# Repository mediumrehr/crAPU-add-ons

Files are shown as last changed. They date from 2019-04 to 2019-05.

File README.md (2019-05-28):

# crAPU-add-ons
a crappy Audio Processing Unit SAO for DEF CON 26 badges; specifically, the zinthesizer was designed for the [DCZia DC26 badge](https://github.com/dczia/Defcon26-Badge) and the scaremin was designed for [Chris Gammell's](https://twitter.com/Chris_Gammell) Goodfear badge.

[video demo](https://www.youtube.com/watch?v=xHMZxM6m_c0)

crAPUs were designed to add audio sythesis/playback capabilities to badges that didn't have any. Since i2c would not be fast enough to drive an external digital to analog converter (DAC), the crAPUs feature their own processor (SAM21G18) to generate tones, and the note and volume can be selected over i2c.

## Installing/Updating Firmware

### Setup

Firmware can be loaded with [Atmel Studio 7.0](https://www.microchip.com/mplab/avr-support/atmel-studio-7), or install the packages below to use with your preferred text editor and compile with arm gcc.

#### arm gcc and gdb

MacOS

```
brew install armmbed/formulae/arm-none-eabi-gcc
```

#### jlink gdb server

Download install file from [segger.com](https://www.segger.com/products/debug-probes/j-link/tools/j-link-gdb-server/about-j-link-gdb-server/)

#### SWD connection

Software debug (SWD) pins are labelled on the back-right of the boards. Connect SWDIO, SWCLK, 3V3, RESET, and GND as labelled. SWD requires the board to be powered external from the SWD port, so it's easiest to power the board from the 3V3 and GND pins on the SAO header.

### Build

```
cd firmware/crAPU/
make -C Build/
```

### Load

#### jlink

Start jlink gdb server in one tab

```
JLinkGDBServer -if SWD -device ATSAMD21G18
```

Start gdb in another tba

```
arm-none-eabi-gdb Build/crAPU.elf
(gdb) target extended-remote :2331
```

Load new firmware, reset microcontroller, and run new code

```
(gdb) load
(gdb) monitor reset
(gdb) c
```

## Usage

The crAPU can be controlled via i2c at address `0x1A`. The add-on will listen for two bytes, the first byte will set the note (0 - 127 using MIDI table), and the second byte will set the volume (0 - 127). If `128 (0x80)` is sent as the MIDI note, it will be interpreted as a note off command.

#### DCZia Badge

Load my [DCZia fork](https://github.com/mediumrehr/Defcon26-Badge) onto the DCZia badge. Attach the zinthesizer add-on, turn on the badge, and within menu mode, select button 7 (left column, third down). The display should now say it's in zinthesizer mode and each key will play a unique note.

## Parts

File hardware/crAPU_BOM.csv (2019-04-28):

DEF CON 26 crAPU Add-on Bill of Materials
April 2019
@mediumrehr
Part | Value | Package | Part Number | Description | Digikey link | notes
C1, 6, 8, 10-12 | 0.1uF | 603 |  | Capacitor
C2 | 0.33uF | 603 |  | Capacitor
C4 | 1uF | 603 |  | Capacitor
C7, 9 | 22pF | 603 |  | Capacitor
D1-3 | white | 1206 |  | LED
J1, (2)* | 2x2 | 0.1" pitch |  | SAO Male header Connector |  | *scaremin requires one; zinthesizer requires two
J3 | 8Ohm/800mW | 15mm Dia. |  | speaker | https://www.digikey.com/product-detail/en/soberton-inc/SP-1504/433-1106-ND/3973690
L1 | FB - 30Ohm | 603 |  | Inductor
R1, 2, 11 | 20K | 805 |  | Resistor
R3-5 | 100 | 603 |  | Resistor
U1 |  | 8-SOIC | LM4862 | IC AMP AUDIO PWR .825W | https://www.digikey.com/product-detail/en/texas-instruments/LM4862MX-NOPB/LM4862MX-NOPBCT-ND/3526986
U4 |  | 48-TQFP | ATSAMD21G18A | IC MCU 32BIT 256KB FLASH | https://www.digikey.com/product-detail/en/microchip-technology/ATSAMD21G18A-AUT/ATSAMD21G18A-AUTCT-ND/4878879
Y1 | 32.768KHz | 2-SMD | ABS06-127-32.768KHZ-T | Crystal | https://www.digikey.com/product-detail/en/abracon-llc/ABS06-127-32.768KHZ-T/535-14513-1-ND/8827204

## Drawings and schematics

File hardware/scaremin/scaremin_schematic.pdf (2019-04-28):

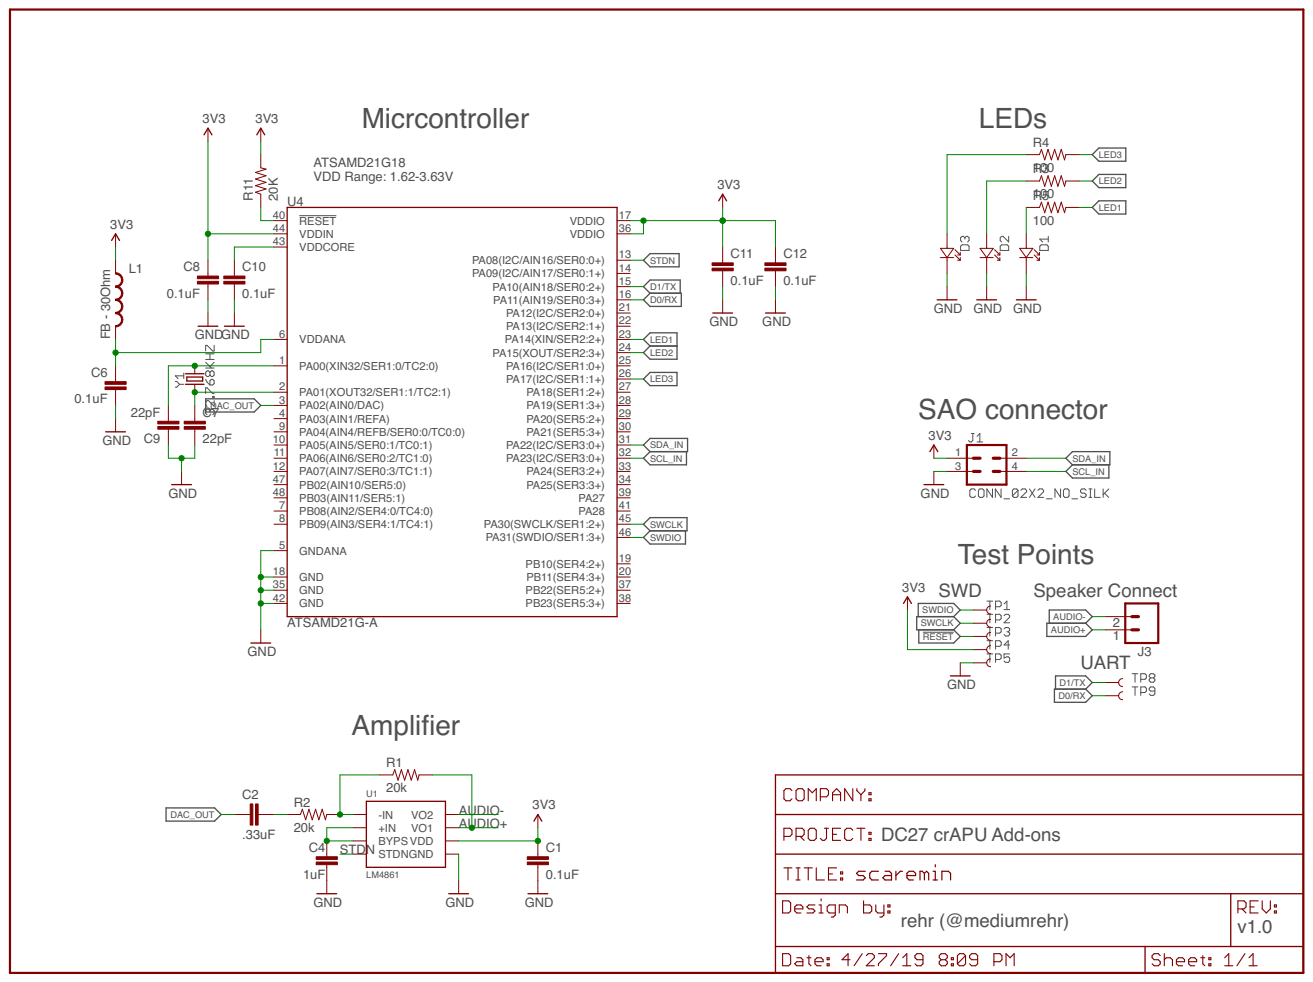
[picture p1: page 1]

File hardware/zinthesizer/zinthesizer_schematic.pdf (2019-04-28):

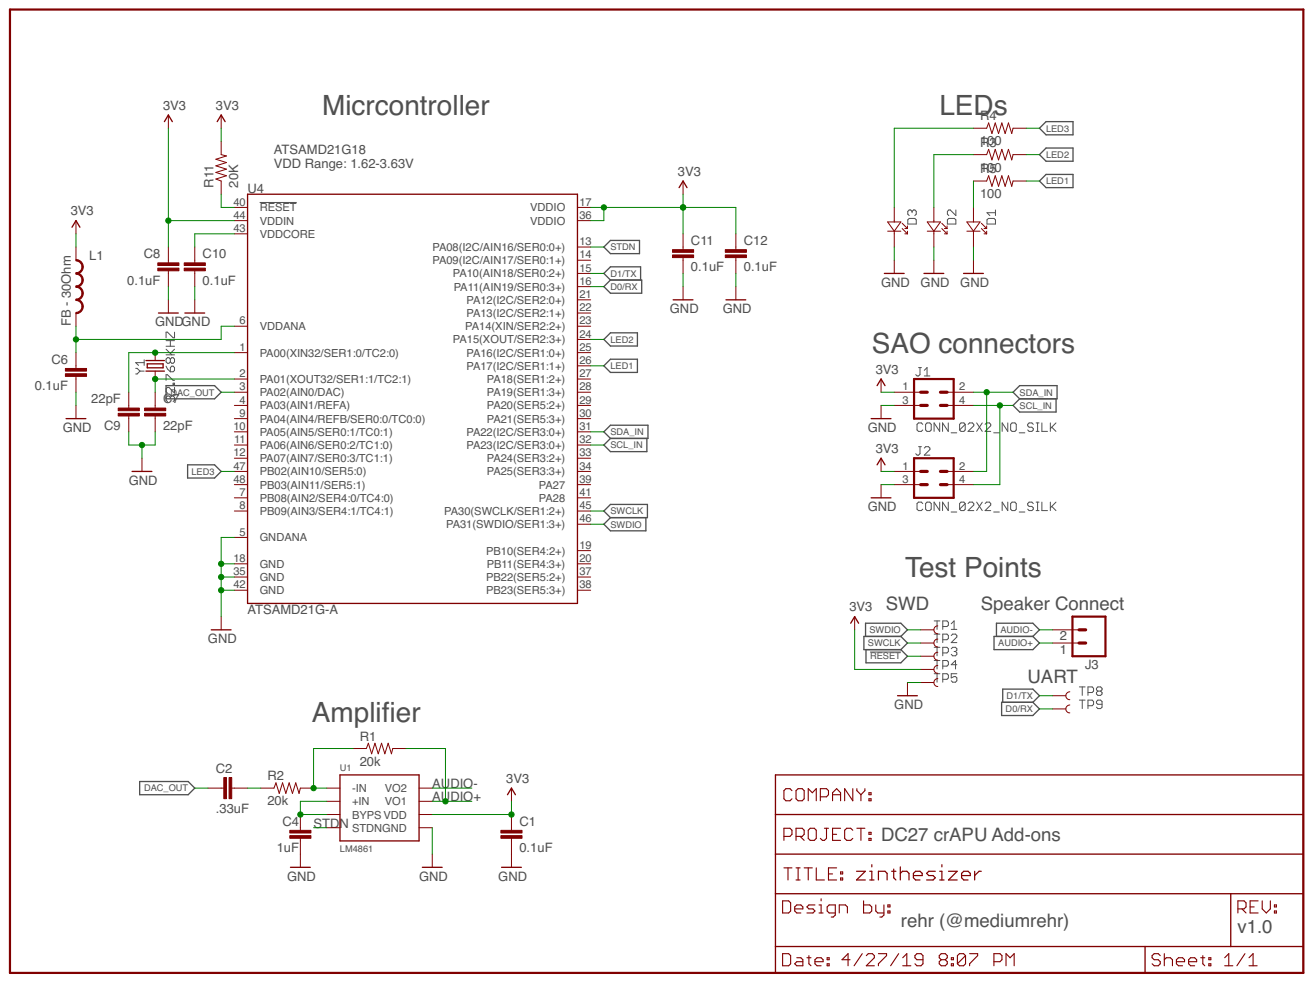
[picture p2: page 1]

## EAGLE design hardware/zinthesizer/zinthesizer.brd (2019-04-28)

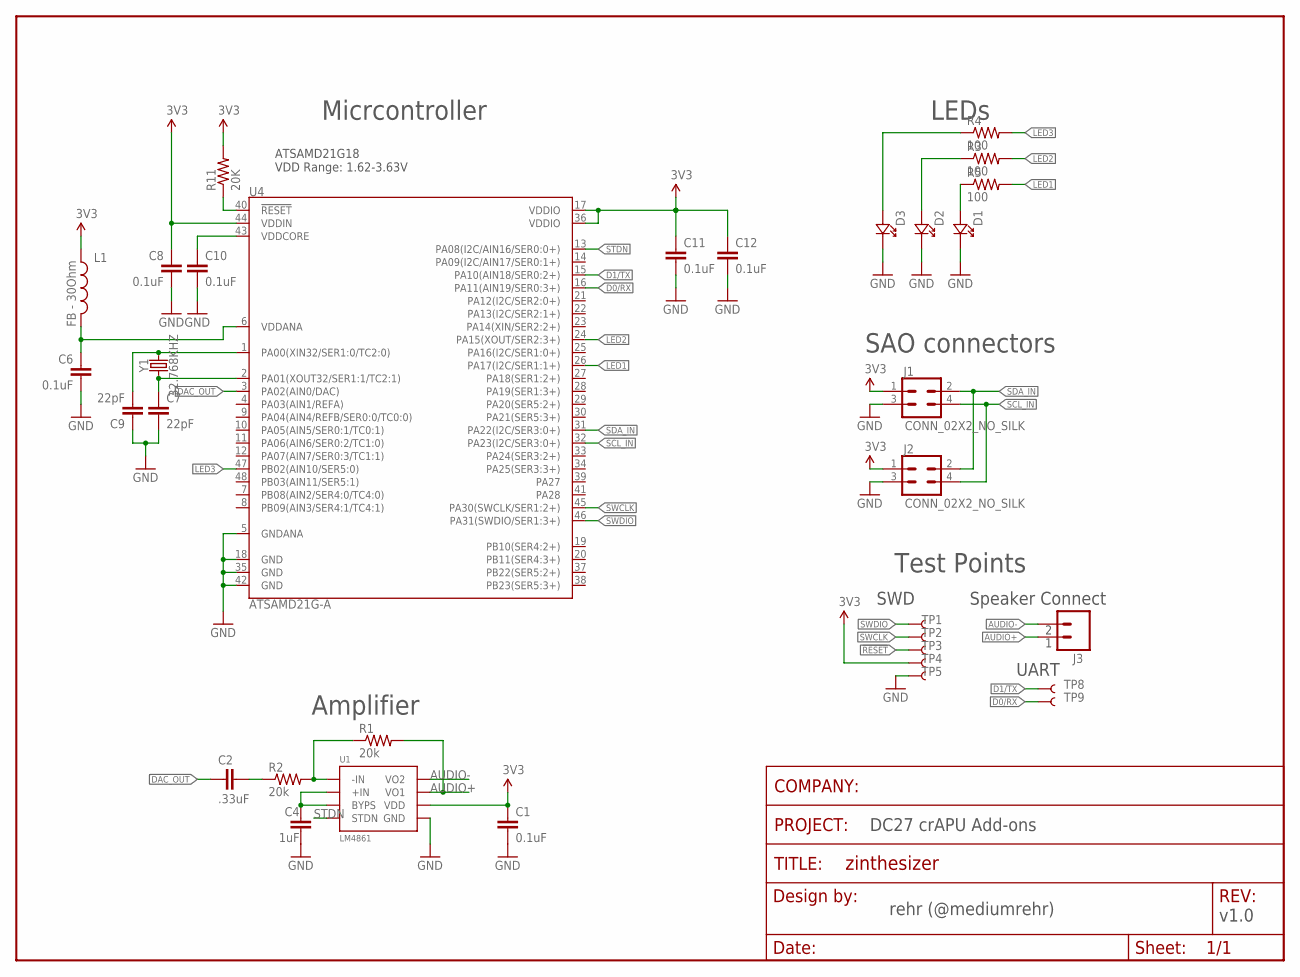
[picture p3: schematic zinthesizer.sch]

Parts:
C1, C6, C8, C10, C11, C12: 0.1uF; 0603-CAP
C2: .33uF; 0603-CAP
C4: 1uF; 0603-CAP
C7, C9: 22pF; 0603-CAP
D1, D2, D3: LED1206REVERSE_NO_SILK; 1206_NO_SILK
FRAME1: FRAME-LETTER-BLANKNO_PACKAGE; DUMMY
J1, J2: CONN_02X2_NO_SILK; 2X2_NO_SILK
J3: M02ROUND; M02_ROUND
L1: FB - 30Ohm; 0603
R1, R2: 20k; 0805
R3, R4, R5: 100; 0603-RES
R11: 20K; 0603-RES
TP1, TP2, TP3, TP4, TP5: TEST-POINT3X5; PAD.03X.05
TP8, TP9: TEST-POINT3X4; PAD.03X.04
U1: LM4861; 8-SOIC
U4: ATSAMD21G-A; TQFP-48
Y1: 32.768KHZ; ABS06

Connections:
3.3V: C1.1, C8.1, C11.1, C12.1, J1.1, J2.1, L1.1, R11.2, TP4.P$1, U1.P$6 (VDD), U4.17 (VDDIO), U4.36 (VDDIO), U4.44 (VDDIN)
!RESET: R11.1, TP3.P$1, U4.40 (!RESET!)
AUDIO+: J3.P$1, R1.2, U1.P$5 (VO1)
AUDIO-: J3.P$2, U1.P$8 (VO2)
D0/RX: TP9.P$1, U4.16 (PA11(AIN19/SER0:3+))
D1/TX: TP8.P$1, U4.15 (PA10(AIN18/SER0:2+))
DAC_OUT: C2.2, U4.3 (PA02(AIN0/DAC))
GND: C1.2, C4.2, C6.2, C7.2, C8.2, C9.1, C10.2, C11.2, C12.2, D1.P$1, D2.P$1, D3.P$1, J1.3, J2.3, TP5.P$1, U1.P$7 (GND), U4.5 (GNDANA), U4.18 (GND), U4.35 (GND), U4.42 (GND)
LED1: R5.2, U4.26 (PA17(I2C/SER1:1+))
LED2: R3.2, U4.24 (PA15(XOUT/SER2:3+))
LED3: R4.2, U4.47 (PB02(AIN10/SER5:0))
unnamed: C2.1, R2.1
unnamed: R1.1, R2.2, U1.P$4 (-IN)
unnamed: D1.P$2, R5.1
unnamed: C7.1, U4.2 (PA01(XOUT32/SER1:1/TC2:1)), Y1.P$1 (1)
unnamed: C4.1, U1.P$2 (BYPS), U1.P$3 (+IN)
unnamed: D2.P$2, R3.1
unnamed: D3.P$2, R4.1
unnamed: C9.2, U4.1 (PA00(XIN32/SER1:0/TC2:0)), Y1.P$2 (2)
SCL_IN: J1.4, J2.4, U4.32 (PA23(I2C/SER3:0+))
SDA_IN: J1.2, J2.2, U4.31 (PA22(I2C/SER3:0+))
STDN: U1.P$1 (STDN), U4.13 (PA08(I2C/AIN16/SER0:0+))
SWCLK: TP2.P$1, U4.45 (PA30(SWCLK/SER1:2+))
SWDIO: TP1.P$1, U4.46 (PA31(SWDIO/SER1:3+))
VDDANA: C6.1, L1.2, U4.6 (VDDANA)
VDDCORE: C10.1, U4.43 (VDDCORE)

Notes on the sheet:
ATSAMD21G18 VDD Range: 1.62-3.63V
DC27 crAPU Add-ons
rehr (@mediumrehr)
v1.0
Micrcontroller
LEDs
SAO connectors
Test Points
Amplifier
SWD
Speaker Connect
UART

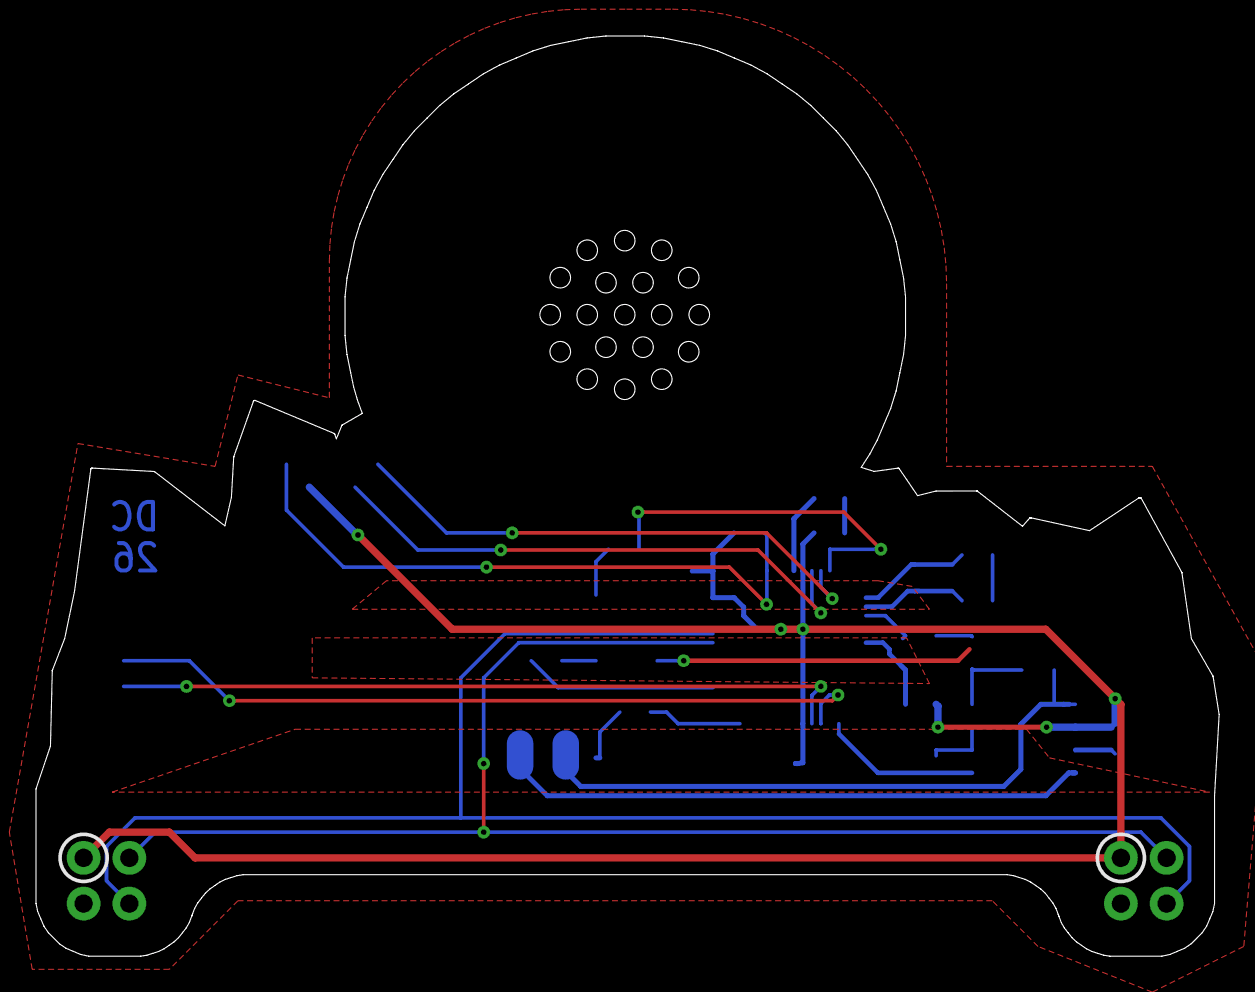
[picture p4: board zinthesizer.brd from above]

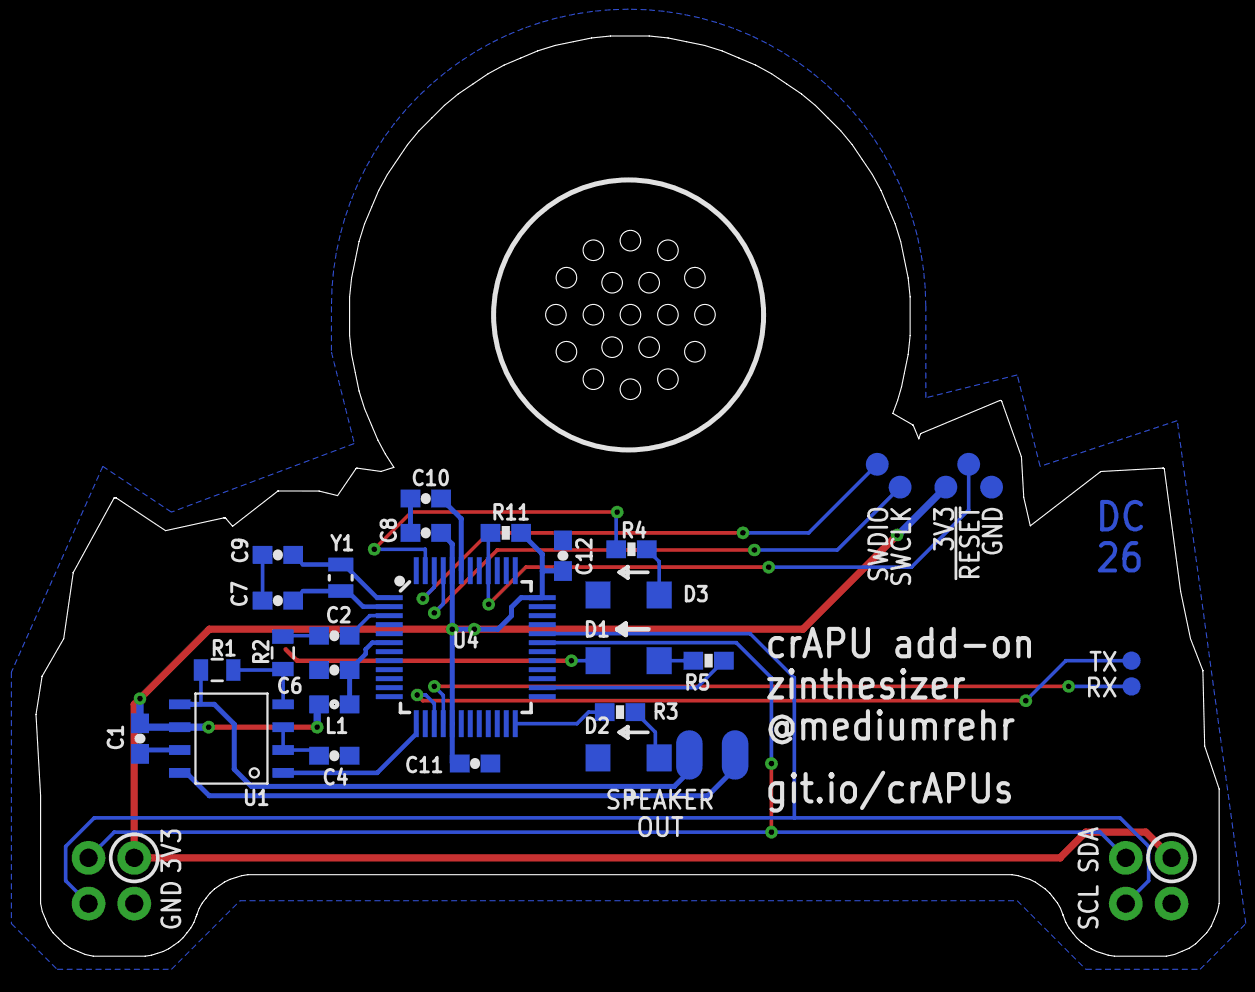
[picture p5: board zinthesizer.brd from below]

Board: 2 copper layers, 65.7 x 51.1 mm, 34 parts (31 on the bottom side), 26 nets.

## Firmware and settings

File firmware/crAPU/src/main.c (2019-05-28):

/**
 * \file
 *
 * \brief Empty user application template
 *
 */

/**
 * \mainpage User Application template doxygen documentation
 *
 * \par Empty user application template
 *
 * Bare minimum empty user application template
 *
 * \par Content
 *
 * -# Include the ASF header files (through asf.h)
 * -# Minimal main function that starts with a call to system_init()
 * -# "Insert application code here" comment
 *
 */

/*
 * Include header files for all drivers that have been imported from
 * Atmel Software Framework (ASF).
 */
/*
 * Support and FAQ: visit <a href="http://www.atmel.com/design-support/">Atmel Support</a>
 */
#include <asf.h>
#include <stdio.h>
#include <math.h>
#include <string.h>

/* Waveform type macros */ 
#define SINE_WAVE		0
#define SAW_TOOTH_WAVE	1
#define TRIANGLE_WAVE	2

/* Waveform selection macro - Selects any one of the three waveforms */
#define WAVE_MODE SINE_WAVE

#define WAVE_RES 32

#define PI 3.14159265358979f

/* Function Prototypes */
void timer_init(void);
void dac_initialize(void);
void configure_i2c_slave(void);
void configure_i2c_slave_callbacks(void);
void evsys_init(void);
void waveforms_init(void);

void i2c_read_request_callback(struct i2c_slave_module *const module);
void i2c_slave_read_complete_callback(struct i2c_slave_module *const module);
void i2c_write_request_callback(struct i2c_slave_module *const module);
void i2c_slave_write_complete_callback(struct i2c_slave_module *const module);

void noteOn(uint8_t newMidiNote, uint8_t newVolume);
void noteOff(void);

/* Driver module structure declaration */
struct tc_module tc_inst;
struct dac_module dac_inst;
struct i2c_slave_module i2c_slave_inst;

#define DATA_LENGTH 10
static struct i2c_slave_packet packet_in;
static uint8_t read_buffer_in [DATA_LENGTH];

/* Other global variables */
uint8_t note = 0;
uint8_t volume = 0;
uint16_t arr_index;
uint16_t nextVal = 0;

uint16_t I2C_ADDR = 0x1A;

// lookup table for midi number to frequency
uint16_t volatile midi_table[128] = { 8, 9, 9, 10, 10, 11, 12, 12, 13, 14, 15, 15, 16, 17, 18, 19, 21, 22, 23, 24, 26, 28, 29, 31, 33, 35, 37, 39, 41, 44, 46, 49, 52, 55, 58, 62, 65, 69, 73, 78, 82, 87, 92, 98, 104, 110, 117, 123, 131, 139, 147, 156, 165, 175, 185, 196, 208, 220, 233, 247, 262, 277, 294, 311, 330, 349, 370, 392, 415, 440, 466, 494, 523, 554, 587, 622, 659, 698, 740, 784, 831, 880, 932, 988, 1047, 1109, 1175, 1245, 1319, 1397, 1480, 1568, 1661, 1760, 1865, 1976, 2093, 2217, 2349, 2489, 2637, 2794, 2960, 3136, 3322, 3520, 3729, 3951, 4186, 4435, 4699, 4978, 5274, 5588, 5920, 6272, 6645, 7040, 7459, 7902, 8372, 8870, 9397, 9956, 10548, 11175, 11840, 12544 };

// waveform tables
// uint16_t sin_table[WAVE_RES] = { 511, 669, 811, 924, 997, 1022, 997, 924, 811, 669, 511, 353, 211, 98, 25, 0, 25, 98, 211, 353 };
// uint16_t saw_table[WAVE_RES] = { 0, 50, 100, 150, 200, 250, 300, 350, 400, 450, 500, 550, 600, 650, 700, 750, 800, 850, 900, 950 };
uint16_t sin_table[WAVE_RES] = { 0 };
uint16_t saw_table[WAVE_RES] = { 0 };
uint16_t tri_table[WAVE_RES] = { 0 };
// volume adjusted table - so don't have to constantly do math that requires many cycles
uint16_t vol_adj_table[WAVE_RES] = { 0 };

/* Timer 3 interrupt handler */
void TC3_Handler(void)
{
	static uint16_t tableIndex = 0;

	TC3->COUNT16.INTFLAG.reg = TC_INTFLAG_MC0;

	// make sure DAC is done setting previous value
	while (dac_inst.hw->STATUS.reg & DAC_STATUS_SYNCBUSY) { ; };
	// set new DAC value
	dac_inst.hw->DATA.reg = vol_adj_table[tableIndex];
	// dac_inst.hw->DATA.reg = sin_table[tableIndex];

	tableIndex = (tableIndex + 1) % WAVE_RES;
}

void i2c_read_request_callback(struct i2c_slave_module *const module)
{
	;
}

void i2c_write_request_callback(struct i2c_slave_module *const module)
{	
	/* Init i2c packet */
	packet_in.data_length = DATA_LENGTH;
	packet_in.data        = read_buffer_in;
	
	/* Read buffer from master */
	i2c_slave_read_packet_job(module, &packet_in);
}

void i2c_slave_write_complete_callback(struct i2c_slave_module *const module) {
	;
}

void i2c_slave_read_complete_callback(struct i2c_slave_module *const module) {
	// destination slave address
	port_pin_set_output_level(LED2_PIN, true);

	uint8_t midiNote = read_buffer_in[0];
	uint8_t velocity = read_buffer_in[1];

	if (midiNote & 0x80) {
		// note off
		noteOff();
	} else {
		// note on
		noteOn(midiNote, velocity);
	}
	
	// toggle LED to show activity
	port_pin_set_output_level(LED2_PIN, false);
}

/* Timer 3 Initialization */
void timer_init(void)
{
	struct tc_config conf_tc;
	struct tc_events conf_tc_events = {.generate_event_on_compare_channel[0] = 1};
	tc_get_config_defaults(&conf_tc);
	conf_tc.clock_source = GCLK_GENERATOR_0;
	conf_tc.clock_prescaler = TC_CLOCK_PRESCALER_DIV1;
	conf_tc.wave_generation = TC_WAVE_GENERATION_MATCH_FREQ;
	conf_tc.counter_16_bit.compare_capture_channel[0] = 0xFFFF;
	tc_init(&tc_inst, TC3, &conf_tc);
	tc_enable_events(&tc_inst, &conf_tc_events);
	tc_enable(&tc_inst);
	tc_stop_counter(&tc_inst);
	/* Enable TC3 match/capture channel 0 interrupt */
	TC3->COUNT16.INTENSET.reg = TC_INTENSET_MC0;
	/* Enable TC3 module interrupt */
	NVIC_EnableIRQ(TC3_IRQn);
}

/* DAC Initialization */
void dac_initialize(void)
{
	struct dac_config conf_dac;
	dac_get_config_defaults(&conf_dac);
	conf_dac.reference = DAC_REFERENCE_AVCC;
	if (dac_init(&dac_inst, DAC, &conf_dac) != STATUS_OK) {
		port_pin_set_output_level(LED0_PIN, true);
	}
	dac_enable(&dac_inst);
}

void configure_i2c_slave(void)
{
	/* Initialize config structure and module instance */
	struct i2c_slave_config config_i2c_slave;
	i2c_slave_get_config_defaults(&config_i2c_slave);

	/* Change address and address_mode */
	config_i2c_slave.address      = I2C_ADDR;
	config_i2c_slave.address_mode = I2C_SLAVE_ADDRESS_MODE_MASK;
	config_i2c_slave.pinmux_pad0  = PINMUX_PA22C_SERCOM3_PAD0;
	config_i2c_slave.pinmux_pad1  = PINMUX_PA23C_SERCOM3_PAD1;

	/* Initialize and enable device with config */
	i2c_slave_init(&i2c_slave_inst, SERCOM3, &config_i2c_slave);

	i2c_slave_enable(&i2c_slave_inst);
}

void configure_i2c_slave_callbacks(void)
{
	/* Register and enable callback functions */
	i2c_slave_register_callback(&i2c_slave_inst, i2c_read_request_callback,
			I2C_SLAVE_CALLBACK_READ_REQUEST);
	i2c_slave_enable_callback(&i2c_slave_inst,
			I2C_SLAVE_CALLBACK_READ_REQUEST);
			
	i2c_slave_register_callback(&i2c_slave_inst, i2c_slave_read_complete_callback,
			I2C_SLAVE_CALLBACK_READ_COMPLETE);
	i2c_slave_enable_callback(&i2c_slave_inst,
			I2C_SLAVE_CALLBACK_READ_COMPLETE);

	i2c_slave_register_callback(&i2c_slave_inst, i2c_write_request_callback,
			I2C_SLAVE_CALLBACK_WRITE_REQUEST);
	i2c_slave_enable_callback(&i2c_slave_inst,
			I2C_SLAVE_CALLBACK_WRITE_REQUEST);
			
	i2c_slave_register_callback(&i2c_slave_inst, i2c_slave_write_complete_callback,
			I2C_SLAVE_CALLBACK_WRITE_COMPLETE);
	i2c_slave_enable_callback(&i2c_slave_inst,
			I2C_SLAVE_CALLBACK_WRITE_COMPLETE);
}

/* Event System Initialization */
void evsys_init(void)
{
	struct events_resource conf_event_resource;
	struct events_config conf_event;
	events_get_config_defaults(&conf_event);
	conf_event.edge_detect = EVENTS_EDGE_DETECT_NONE;
	conf_event.path = EVENTS_PATH_ASYNCHRONOUS;
	conf_event.generator = EVSYS_ID_GEN_TC3_MCX_0;
	events_allocate(&conf_event_resource, &conf_event);
	events_attach_user(&conf_event_resource, EVSYS_ID_USER_DAC_START);
}

/* Initialize the waveform buffers with output data */
void waveforms_init(void)
{
	uint8_t i;

	for (i = 0; i < WAVE_RES; i++) {
		sin_table[i] = (uint16_t)(511 + (511.0 * sin(2.0 * PI * (double)i / WAVE_RES)));
		saw_table[i] = (uint16_t)(1023.0 * (double)i / (WAVE_RES - 1));
	}
	uint8_t halfWaveRes = WAVE_RES / 2;
	for (i = 0; i < halfWaveRes; i++) {
		tri_table[i] = (uint16_t)(1023.0 * (double)i / (double)halfWaveRes);
	}
	for (i = 0; i < (WAVE_RES - halfWaveRes); i++) {
		tri_table[i] = 1023 - (uint16_t)(1023.0 * (double)i / WAVE_RES);
	}
}

static void config_pins(void)
{
	struct port_config pin_conf;
	port_get_config_defaults(&pin_conf);

	pin_conf.direction  = PORT_PIN_DIR_OUTPUT;
	port_pin_set_config(LED0_PIN, &pin_conf);
	port_pin_set_config(LED1_PIN, &pin_conf);
	port_pin_set_config(LED2_PIN, &pin_conf);
	port_pin_set_config(PIN_PA08, &pin_conf); // shutdown
	port_pin_set_output_level(LED0_PIN, false);
	port_pin_set_output_level(LED1_PIN, false);
	port_pin_set_output_level(LED2_PIN, false);
	port_pin_set_output_level(PIN_PA08, true);
}

void noteOn(uint8_t newMidiNote, uint8_t newVolume) {

	volume = newVolume;
	for (uint8_t i=0; i < WAVE_RES; i++) {
		vol_adj_table[i] = (uint16_t)((float)sin_table[i] * ((float)volume / 127.0));
	}
	
	if ((note != newMidiNote) && (newMidiNote < 128)) {
		// set new note and frequency
		note = newMidiNote;
		uint16_t freq = midi_table[note];
		
		// update timer trigger for new frequency
		tc_set_compare_value(&tc_inst, 0, system_gclk_gen_get_hz(GCLK_GENERATOR_0)/(freq*WAVE_RES) - 1);
		
		// enable amplifier
		port_pin_set_output_level(PIN_PA08, false);
	}
}

void noteOff() {
	// disable amplifier
	port_pin_set_output_level(PIN_PA08, true);

	// set freq to zero
	note = 128; // note off
}

uint16_t volatile delay(uint16_t millis) {
	for (uint16_t j=millis; j>0; j--) {
		for (uint16_t i=650; i>0; i--) { ; }
	}
}

/* Main function */
int main(void)
{
	system_init();
	timer_init();
	config_pins();
	dac_initialize();
	configure_i2c_slave();
	configure_i2c_slave_callbacks();
	evsys_init();
	waveforms_init();

	/* Start TC3 timer */
	tc_start_counter(&tc_inst);
	/* Enable global interrupt */
	system_interrupt_enable_global();
	
	while (true) {

	}
}

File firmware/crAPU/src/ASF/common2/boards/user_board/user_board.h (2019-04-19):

/**
 * \file
 *
 * \brief User board definition template
 *
 */

 /* This file is intended to contain definitions and configuration details for
 * features and devices that are available on the board, e.g., frequency and
 * startup time for an external crystal, external memory devices, LED and USART
 * pins.
 */
/*
 * Support and FAQ: visit <a href="http://www.atmel.com/design-support/">Atmel Support</a>
 */

#ifndef USER_BOARD_H
#define USER_BOARD_H

#include <conf_board.h>

#ifdef __cplusplus
extern "C" {
#endif

/**
 * \ingroup group_common_boards
 * \defgroup user_board_group User board
 *
 * @{
 */

void system_board_init(void);

/** Name string macro */
#define BOARD_NAME                "USER_BOARD"

/** \name Resonator definitions
 *  @{ */
#define BOARD_FREQ_SLCK_XTAL      (32768U)
#define BOARD_FREQ_SLCK_BYPASS    (32768U)
#define BOARD_FREQ_MAINCK_XTAL    0 /* Not Mounted */
#define BOARD_FREQ_MAINCK_BYPASS  0 /* Not Mounted */
#define BOARD_MCK                 CHIP_FREQ_CPU_MAX
#define BOARD_OSC_STARTUP_US      15625
/** @} */

/** \name LED0 definitions
 *  @{ */
#define LED0_PIN                  PIN_PA14
#define LED0_ACTIVE               false
#define LED0_INACTIVE             !LED0_ACTIVE
/** @} */

/** \name LED1 definitions
 *  @{ */
#define LED1_PIN                  PIN_PA15
#define LED1_ACTIVE               false
#define LED1_INACTIVE             !LED1_ACTIVE
/** @} */

/** \name LED2 definitions
 *  @{ */
#define LED2_PIN                  PIN_PA17
#define LED2_ACTIVE               false
#define LED2_INACTIVE             !LED2_ACTIVE
/** @} */

/** \name SW0 definitions
 *  @{ */
#define SW0_PIN                   PIN_PA15
#define SW0_ACTIVE                false
#define SW0_INACTIVE              !SW0_ACTIVE
#define SW0_EIC_PIN               PIN_PA15A_EIC_EXTINT15
#define SW0_EIC_MUX               MUX_PA15A_EIC_EXTINT15
#define SW0_EIC_PINMUX            PINMUX_PA15A_EIC_EXTINT15
#define SW0_EIC_LINE              15
/** @} */

/**
 * \name LED #0 definitions
 *
 * Wrapper macros for LED0
 *
 *  @{ */
#define LED_0_NAME                "LED0 (yellow)"
#define LED_0_PIN                 LED0_PIN
#define LED_0_ACTIVE              LED0_ACTIVE
#define LED_0_INACTIVE            LED0_INACTIVE
#define LED0_GPIO                 LED0_PIN
#define LED0                      LED0_PIN

#define LED_0_PWM4CTRL_MODULE     TCC0
#define LED_0_PWM4CTRL_CHANNEL    0
#define LED_0_PWM4CTRL_OUTPUT     0
#define LED_0_PWM4CTRL_PIN        PIN_PB30E_TCC0_WO0
#define LED_0_PWM4CTRL_MUX        MUX_PB30E_TCC0_WO0
#define LED_0_PWM4CTRL_PINMUX     PINMUX_PB30E_TCC0_WO0
/** @} */

/** Number of on-board LEDs */
#define LED_COUNT                 1

/**
 * \name Serialflash definitions
 *
 * On board Serialflash definitions.
 *
 *  @{ */
#define SERIALFLASH_SPI_MODULE      SERCOM5
#define SERIALFLASH_SPI_MUX_SETTING SPI_SIGNAL_MUX_SETTING_E
#define SERIALFLASH_SPI_PINMUX_PAD0 PINMUX_PB16C_SERCOM5_PAD0
#define SERIALFLASH_SPI_PINMUX_PAD1 PINMUX_UNUSED
#define SERIALFLASH_SPI_PINMUX_PAD2 PINMUX_PB22D_SERCOM5_PAD2
#define SERIALFLASH_SPI_PINMUX_PAD3 PINMUX_PB23D_SERCOM5_PAD3
#define SERIALFLASH_SPI_CS PIN_PA13
/** @} */

/**
 * \name Button #0 definitions
 *
 * Wrapper macros for SW0
 *
 *  @{ */
#define BUTTON_0_NAME             "SW0"
#define BUTTON_0_PIN              SW0_PIN
#define BUTTON_0_ACTIVE           SW0_ACTIVE
#define BUTTON_0_INACTIVE         SW0_INACTIVE
#define BUTTON_0_EIC_PIN          SW0_EIC_PIN
#define BUTTON_0_EIC_MUX          SW0_EIC_MUX
#define BUTTON_0_EIC_PINMUX       SW0_EIC_PINMUX
#define BUTTON_0_EIC_LINE         SW0_EIC_LINE
/** @} */

/** Number of on-board buttons */
#define BUTTON_COUNT 1

/** @} */

#ifdef __cplusplus
}
#endif

#endif // USER_BOARD_H

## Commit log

2019-04-26 enable DAC (only 440Hz output)
2019-04-27 add i2c AND basic pitch control over i2c
2019-04-28 add hardware design files and BOM
    [crAPU_BOM.csv, scaremin.brd, scaremin.sch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]
2019-05-28 fix i2c address

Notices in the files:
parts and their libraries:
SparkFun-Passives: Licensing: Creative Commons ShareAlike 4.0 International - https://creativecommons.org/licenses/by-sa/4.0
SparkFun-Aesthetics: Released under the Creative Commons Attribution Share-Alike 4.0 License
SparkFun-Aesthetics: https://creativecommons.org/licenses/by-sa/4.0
